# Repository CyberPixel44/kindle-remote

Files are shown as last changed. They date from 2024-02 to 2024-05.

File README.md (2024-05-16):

# Kindle Accessibility Remote Control
A project that allows for easy, low-latency wireless remote control of a Kindle e-reader running Koreader.
This project was inspired by my lovely Grandfather, Dr. A.M.V. Reddy, who still loves to read books to this day!

## Acknowledgement
Big thanks to user [bneo99](https://github.com/bneo99) for the base concept to build this project with!

# Setup

## Kindle

### Jailbreak
For most up to date jailbreak info, monitor the mobilread forums

\[UPDATED JUL 23]

[Forum Help](https://www.mobileread.com/forums/showthread.php?t=356872)
Download [relevant files](https://github.com/notmarek/LanguageBreak/releases/latest).
Instructions from [notmarek](https://github.com/notmarek/LanguageBreak):

Warnings

    ⚠️ This method will DELETE all content on your device. Backup important files.
    ⚠️ This method works up to firmware version 5.16.2.1.1. It is strongly suggested you upgrade to this firmware before starting.
    ⚠️ Do not update your firmware beyond 5.16.2.1.1 after jailbreaking with LanguageBreak, as future versions of the firmware patch it.
    ⚠️ Your device must have no password lock. Remove it before starting.

Before you start, make sure:

    Airplane Mode is ON
    The device (esp. the root folder) should have no .bin or update.bin.tmp.partial files before you start. This may be a pending OTA update. Delete them.

Jailbreaking your Kindle

    Type ;enter_demo into the Kindle search bar, press enter, then reboot the device.
    Once the device boots, dismiss the wifi selection dialog, type whatever you'd like into the text fields, then continue.
    Select Skip, then Standard, then Done
    The device will take a few minutes to go into demo mode. When it's done, use this gesture to access the main screen.
    Type ;demo into the Kindle search bar, then press enter to access the Demo Mode Configuration screen.
    Select the Sideload Content option.
    Connect your Kindle to a PC, then copy the contents of the LanguageBreak folder to the Kindle's root directory (if prompted, overrwrite the existing files).
    Eject, then unplug your Kindle, then return to the Demo Configuration Screen (using the method in step 5, if required).
    Select Resell Device, then confirm.
    As soon as the "Press the Power Button" screen appears, plug your Kindle back into your computer. (This is time sensitive, be quick.)
    Copy the contents of the LanguageBreak folder to the Kindle's root directory, again. (if prompted, overrwrite the existing files).
    After all files have been written, eject your Kindle, then press and hold the power button until the unit reboots.
    At this point, a language selection screen appears. Select 简体中文 (Chinese), which should appear above an entry called Pseudot and below Japanese.
    Your Kindle should reboot, and some log messages should appear in the top right-hand corner.

Applying the Hotfix

    After the device has rebooted, type ;uzb into the Kindle search bar to enable USB access within demo mode, then press enter.
    Connect the device to a PC and copy whichever Update_hotfix_languagebreak-{languge/locale}.bin file matches your language to the Kindle's root directory.
    Eject your Kindle, then ;dsts into the Kindle search bar to access the settings page. Locate the Update your Kindle option and press it, then confirm.

    Using your phone to translate the menus is helpful if you don't happen to be able to read Chinese.

This will reboot the device out of Demo mode. Your device may go into Managed mode after completing these steps. Managed devices have some settings greyed out, and ask the user to contact their system administrator. See below for steps on how to restore functionality (and the correct language) to your device.
Restoring the Correct Language and Exiting Managed Mode
If your kindle is not registered to an Amazon account:

    Type ;demo into the Kindle search bar.
    You will get a prompt with two buttons. Press the right-most button.
    The device will reboot. If all is well, your Kindle should have a folder named mkk in the root directory.

If your kindle is registered to an Amazon account:

    Enter ;enter_demo into the Kindle search bar, then reboot your device.
    The device will be back in full "Demo Mode". Use the same gesture to access the main screen.
    Enter ;demo into the Kindle search bar.
    Select Resell device, then confirm.
    The device will reboot. If all is well, your Kindle should have a folder named mkk in the root directory.

### WiFi
The Kindle won't allow you to connect to a network that has no Internet access by default.
In the topmost level of USB storage, create the file named `WIFI_NO_NET_PROBE` (all capitals, no extension, no contents).
This has to be done when Koreader is NOT launched.
Once you've connected the Kindle to the network once, you do not need to mess with the Kindle's default WiFi settings.
You may turn on Airplane mode if you are afraid of losing your jailbreak.

### Koreader
Before installing Koreader, you must install KUAL:
- Download `MR Package Installer` from [mobilread](https://www.mobileread.com/forums/showthread.php?t=225030).
- Extract. Copy all files to Kindle.
- Download `KUAL (coplate).` from [mobilread](https://www.mobileread.com/forums/showthread.php?t=225030).
- Extract it and put `Update_KUALBooklet_ff4134d_install.bin` in the `mrpackages` folder on the kindle and enter `;log mrpi` into the search bar (where you search for books).
- Read [this section at the end of this page to](https://github.com/koreader/koreader/wiki/Installation-on-Kindle-devices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) figure out which Kindle release you want to download.
- Download the latest Kindle package from this page.
- Unzip the whole archive into the Kindle's USB root directory

After installing Koreader, extract the contents of the `plugins` directory provided in this repository into the `koreader` folder of the Kindle found in the root of the Kindle. (`koreader/plugins/httpremote.koplugin/...`)

Once setup, you can find the plugin menu in the toolbar of Koreader. I suggest enabling autostart to start the listening server on the Kindle whenever turned on.
Turn on WiFi from Koreader ONLY! If you turn on WiFi in the main OS, you may run the risk of updating your Kindle and losing your jailbreak.
Your Koreader should automatically connect to the KindleRemote access point, as you configured it previously.

## ESP32
Any ESP32-based dev board that supports WiFi AP can be utilized for this project.
[LILYGO's T-Lion board](https://www.lilygo.cc/products/t-lion) works great for this project, as it comes with a 5-way joystick and 18650 li-ion charging circuit which is ideal for remote operations.



### Flashing KindleWiFiRemote.ino
If using the Arduino IDE,
1. In your Arduino IDE, go to File > Preferences
2. Enter the following into the “Additional Board Manager URLs” field:

   `https://raw.githubusercontent.com/espressif/arduino-esp32/gh-pages/package_esp32_index.json`
4. Open the Boards Manager: Go to Tools > Board > Boards Manager…
5. Search for ESP32 and press install button for the `“ESP32 by Espressif Systems“`
6. Select your Board in Tools > Board menu
   - For the case of the T-Lion, use ESP32 Wrover Kit (all versions)
7. Upload the code after selecting the COM port

### Dependencies

- [WiFi.h](https://github.com/espressif/arduino-esp32/blob/master/libraries/WiFi/src/WiFi.h)
- esp_wifi.h

### Configuration

1. **Wi-Fi AP Configuration:**
   - SSID: `KindleRemote`
   - Password: `password`

2. **ESP32 Pin Configuration:**
   These pins are default for the T-Lion
   - Forward Button: Pin 36
   - Toggle Button: Pin 39
   - Down Button: Pin 33
   - Backward Button: Pin 34
   - Up Button: Pin 32

3. **Kindle Static IP Address:**
   - The Kindle will normally get assigned the same default IP whenever connected to the ESP32's AP
   - To determine this (only has to be done once), open `Network Settings` in Koreader and click on `Network Info` to view the Kindle's local IP address
   - Replace the field with this local address: `Kindle IP: <local_IP>`
  
### 3D Printed Enclosure
To protect the ESP32 T-Lion from LILYGO, I designed 3D printable models that enclose the remote.
The STL files can be found in this repository as `Remote Bottom.stl` and `Remote Top.stl`



To print, simply slice them in slicing software such as [Ultimaker Cura](https://ultimaker.com/software/ultimaker-cura/) and print!




Mounting the base is tricky:

**⚠️ WARNING: The remote DOES NOT SLIDE IN! You will damage some traces and resistors!!!**
1) Insert one of the edges directly into the groove from above such that the remote sits at an angle with one edge completely inside the groove and the other sticking out.
2) Gently press down on the edge that is sticking out and pull back on the casing with your other hand to force the grooves around and on top of the other side.
3) Adjust the forwards and backwards position to seat the board properly.

# Usage

1. Turn on ESP-Remote.
2. Connect the Kindle to the Wi-Fi network named `KindleRemote` (or equivalent if changed).
3. Press the corresponding buttons on your ESP32 to control the Kindle remotely:

   - Forward Button (`buttonPinForward`): Page forward.
   - Toggle Button (`buttonPinToggle`): Toggle night mode.
   - Down Button (`buttonPinDown`): Decrease brightness.
   - Backward Button (`buttonPinBackward`): Page backward.
   - Up Button (`buttonPinUp`): Increase brightness.

## Latency

By viewing dynamic logs on Koreader, there is a ~20ms latency between when the button is pressed to when the page turn command is issued (wireless + software latency). However, same as with using the touchscreen, there is a considerable latency of ~200ms to ~600ms for the page to actually refresh due to e-ink hardware limitations of the Kindle itself!

## Disclaimer

This script is provided as-is, and you should use it responsibly. Ensure that you have the necessary permissions to control your Kindle remotely. The script assumes a certain setup and may require adjustments based on your specific environment. Jailbreaking your Kindle may void your warranty.

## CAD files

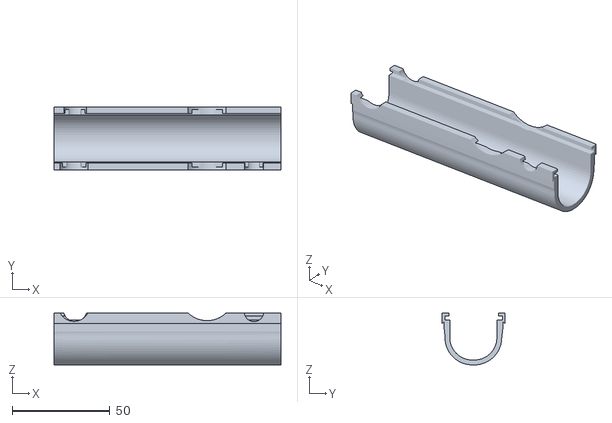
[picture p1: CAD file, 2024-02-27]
Remote Bottom.stl
116.0 x 32.0 x 26.5

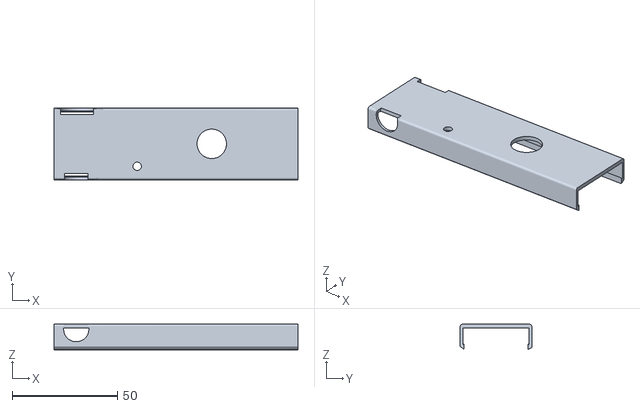
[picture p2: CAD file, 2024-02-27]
Remote Top.stl
116.0 x 34.0 x 12.2

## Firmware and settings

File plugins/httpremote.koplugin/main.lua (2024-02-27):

-- Original by https://github.com/bneo99

local Device =  require("device")
local UIManager = require("ui/uimanager")
local WidgetContainer = require("ui/widget/container/widgetcontainer")
local Event = require("ui/event")
local logger = require("logger")
local _ = require("gettext")

local HttpRemote = WidgetContainer:extend{
    name = "httpremote",
    is_doc_only = true,
}

function HttpRemote:init()
    self.port = G_reader_settings:readSetting("httpremote_port", "8080")
    self.autostart = G_reader_settings:isTrue("httpremote_autostart")

    if self.autostart then
        self:start()
    end

    self.ui.menu:registerToMainMenu(self)
end

function HttpRemote:initHttpMQ(host, port)
    local StreamMessageQueueServer = require("ui/message/streammessagequeueserver")
    if self.http_socket == nil then
        self.http_socket = StreamMessageQueueServer:new{
            host = host,
            port = port,
            receiveCallback = self:onRequest(),
        }
        self.http_socket:start()
        self.http_messagequeue = UIManager:insertZMQ(self.http_socket)
    end
    logger.info(string.format("connecting to calibre @ %s:%s", host, port))
end

function HttpRemote:onEnterStandby()
    logger.dbg("HttpRemote: onEnterStandby")
    self:stop()
end

function HttpRemote:onSuspend()
    logger.dbg("HttpRemote: onSuspend")
    self:stop()
end

function HttpRemote:onExit()
    logger.dbg("HttpRemote: onExit")
    self:stop()
end

function HttpRemote:onCloseWidget()
    logger.dbg("HttpRemote: onCloseWidget")
    self:stop()
end

function HttpRemote:onLeaveStandby()
    logger.dbg("HttpRemote: onLeaveStandby")
    if self.http_socket == nil then
        self:start()
    end
end

function HttpRemote:onResume()
    logger.dbg("HttpRemote: onResume")
    if self.http_socket == nil then
        self:start()
    end
end

function HttpRemote:start()
    -- Make a hole in the Kindle's firewall
    if Device:isKindle() then
        os.execute(string.format("%s %s %s",
            "iptables -A INPUT -p tcp --dport", self.port,
            "-m conntrack --ctstate NEW,ESTABLISHED -j ACCEPT"))
        os.execute(string.format("%s %s %s",
            "iptables -A OUTPUT -p tcp --sport", self.port,
            "-m conntrack --ctstate ESTABLISHED -j ACCEPT"))
    end

    self:initHttpMQ("*", self.port)
    logger.dbg("HttpRemote: Server listening on port " .. self.port)
end

function HttpRemote:stop()
    logger.info("HttpRemote: Stopping server...")

    if self.http_socket then
        self.http_socket:stop()
        self.http_socket = nil
    end
    if self.http_messagequeue then
        UIManager:removeZMQ(self.http_messagequeue)
        self.http_messagequeue = nil
    end

    logger.dbg("HttpRemote: Server stopped.")

    -- Plug the hole in the Kindle's firewall
    if Device:isKindle() then
        os.execute(string.format("%s %s %s",
            "iptables -D INPUT -p tcp --dport", self.port,
            "-m conntrack --ctstate NEW,ESTABLISHED -j ACCEPT"))
        os.execute(string.format("%s %s %s",
            "iptables -D OUTPUT -p tcp --sport", self.port,
            "-m conntrack --ctstate ESTABLISHED -j ACCEPT"))
    end
end

function HttpRemote:onRequest(host, port)
    -- NOTE: Closure trickery because we need a reference to *this* self *inside* the callback,
    --       which will be called as a function from another object (namely, StreamMessageQueue).
    local this = self
    return function(data, id_frame)
        local request = string.match(data, "[^\n]+") or ""
        logger.dbg("HttpRemote: Received request: " .. request)
        local params_string = request:match("%u+%s+%S+%?([^%s]+)%s+%S+") -- extract params
        logger.dbg("HttpRemote: Params: ", params_string)

        local params_arr = {}

        if params_string then
            for params in string.gmatch(params_string, "[^&]+") do
                -- Split each parameter string into key and value using string.match
                local key, value = string.match(params, "(.-)=(.*)")
                if key and value then
                    params_arr[key] = value
                end
            end
        end

        local response = "HTTP/1.1 200 OK" -- start of response header

        if params_arr["action"] == "nextpage" then
            this:turnPage(1)
        elseif params_arr["action"] == "prevpage" then
            this:turnPage(-1)
        elseif params_arr["action"] == "increasebrightness" then
            this:changeBrightness("IncreaseFlIntensity")
        elseif params_arr["action"] == "decreasebrightness" then
            this:changeBrightness("DecreaseFlIntensity")
        elseif params_arr["action"] == "togglefrontlight" then
            this:toggleSetting("ToggleFrontlight")
        elseif params_arr["action"] == "togglenightmode" then
            this:toggleSetting("ToggleNightMode")
        elseif params_arr["action"] == "fullrefresh" then
            this:refreshScreen()
        else
            response = response .. "\r\nContent-Type: text/html"
        end

        response = response .. "\r\n\r\n" -- end of response header

        -- response body (if available)
        -- if loadpage param is populated, load the html
        if next(params_arr) == nil or params_arr["loadpage"] then
            response = response .. [[
<html><body>
<p>
<a href="/?action=prevpage&loadpage=1">Previous Page</a>
<a href="/?action=nextpage&loadpage=1">Next Page</a>
<a href="/?action=increasebrightness&loadpage=1">Increase Brightness</a>
<a href="/?action=decreasebrightness&loadpage=1">Decrease Brightness</a>
<a href="/?action=togglefrontlight&loadpage=1">Toggle Frontlight</a>
<a href="/?action=togglenightmode&loadpage=1">Toggle Dark Mode</a>
<a href="/?action=fullrefresh&loadpage=1">Refresh Screen</a>
</p>
</body></html>
            ]]
        end
        logger.dbg("HttpRemote: Sending response: " .. response)
        this.http_socket:send(response, id_frame) -- send the response back to the client
    end
end

function HttpRemote:turnPage(pages)
    local top_wg = UIManager:getTopmostVisibleWidget() or {}
    if top_wg.name == "ReaderUI" then
        logger.dbg("HttpRemote: Sent event GotoViewRel " .. pages)
        self.ui:handleEvent(Event:new("GotoViewRel", pages))
    end
end

-- https://github.com/koreader/koreader/blob/master/frontend/dispatcher.lua
-- link for all supported actions

-- brightness actions
function HttpRemote:changeBrightness(action)
    logger.dbg("HttpRemote: Sent event " .. action .. " 1")
    self.ui:handleEvent(Event:new(action, 1))
    self.ui:handleEvent(Event:new("ShowFlDialog"))
end

-- setting actions (frontlight, nightmode)
function HttpRemote:toggleSetting(action)
    self.ui:handleEvent(Event:new(action))
end

function HttpRemote:refreshScreen()
    self.ui:handleEvent(Event:new("FullRefresh"))
end

function HttpRemote:addToMainMenu(menu_items)
    menu_items.httpremote = {
        text = _("HTTP Remote Control"),
        sorting_hint = ("tools"),
        sub_item_table = {
            {
                text_func = function()
                    if self.http_socket then
                        return _("Stop server")
                    else
                        return _("Start server")
                    end
                end,
                separator = true,
                callback = function()
                    if not self.http_socket then
                        self:start()
                    else
                        self:stop()
                    end
                end,
            },
            {
                text = _("Auto start server"),
                checked_func = function()
                    return self.autostart
                end,
                callback = function()
                    G_reader_settings:toggle("httpremote_autostart")
                    self.autostart = G_reader_settings:isTrue("httpremote_autostart")
                end,
            },
            {
                text_func = function()
                    return "Port: " .. self.port
                end,
                callback = function()
                    local InputDialog = require("ui/widget/multiinputdialog")
                    local port_dialog

                    port_dialog = InputDialog:new{
                        title = _("Set custom port"),
                        fields = {
                            {
                                text = self.port,
                                input_type = "number",
                                hint = _("Port"),
                            },
                        },
                        buttons =  {
                            {
                                {
                                    text = _("Cancel"),
                                    id = "close",
                                    callback = function()
                                        UIManager:close(port_dialog)
                                    end,
                                },
                                {
                                    text = _("OK"),
                                    callback = function()
                                        local port_dialog_input = port_dialog:getInputValue()
                                        if port_dialog_input ~= "" then
                                            local input_port = tonumber(port_dialog_input)
                                            if not input_port or input_port < 1 or input_port > 65355 then
                                                --default port
                                                input_port = 8080
                                            end
                                            self.port = input_port
                                            G_reader_settings:saveSetting("httpremote_port", input_port)

                                            --restart the server
                                            if self.http_socket then
                                                self:stop()
                                                self:start()
                                            end
                                        end
                                        UIManager:close(port_dialog)
                                    end,
                                },
                            },
                        },
                    }
                    UIManager:show(port_dialog)
                    port_dialog:onShowKeyboard()
                end,
            }
        },
    }
end

return HttpRemote

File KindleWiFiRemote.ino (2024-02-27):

#include <WiFi.h> // Include the Wi-Fi library
#include "esp_wifi.h"

const char *ssid = "KindleRemote"; // The name of the Wi-Fi network that will be created
const char *password = "password"; // The password required to connect to it

// kindle IP address
byte ip[] = {192, 168, 4, 2};
const char *host = "192.168.4.2";

#define buttonPinForward 36
#define buttonPinToggle 39
#define buttonPinDown 33
#define buttonPinBackward 34
#define buttonPinUp 32

bool lastButtonStateForward = HIGH;  // initial state is not pressed
bool lastButtonStateToggle = HIGH;   // initial state is not pressed
bool lastButtonStateDown = HIGH;     // initial state is not pressed
bool lastButtonStateBackward = HIGH; // initial state is not pressed
bool lastButtonStateUp = HIGH;       // initial state is not pressed

WiFiClient client;

void setup()
{

  setCpuFrequencyMhz(80); // decreases battery drain over 2x! (30mA) vs (63mA original)

  pinMode(buttonPinForward, INPUT_PULLUP);  // forward button pin
  pinMode(buttonPinToggle, INPUT_PULLUP);   // toggle button pin
  pinMode(buttonPinDown, INPUT_PULLUP);     // down button pin
  pinMode(buttonPinBackward, INPUT_PULLUP); // backward button pin
  pinMode(buttonPinUp, INPUT_PULLUP);       // up button pin

  Serial.begin(115200);
  delay(10);
  Serial.println('\n');

  WiFi.softAP(ssid, password); // Start the access point
  Serial.print("Access Point \"");
  Serial.print(ssid);
  Serial.println("\" started");

  Serial.print("IP address:\t");
  Serial.println(WiFi.softAPIP()); // Send the IP address of the ESP8266 to the computer

  delay(1000);
}

void loop()
{
  // debounce button code for perfect button listening :)
  // read button Forward
  bool buttonStateForward = digitalRead(buttonPinForward);
  if (buttonStateForward != lastButtonStateForward && buttonStateForward == LOW)
  {
    PageForward();
  }
  lastButtonStateForward = buttonStateForward;

  // read button Toggle
  bool buttonStateToggle = digitalRead(buttonPinToggle);
  if (buttonStateToggle != lastButtonStateToggle && buttonStateToggle == LOW)
  {
    ToggleNightMode();
  }
  lastButtonStateToggle = buttonStateToggle;

  // read button Down
  bool buttonStateDown = digitalRead(buttonPinDown);
  if (buttonStateDown != lastButtonStateDown && buttonStateDown == LOW)
  {
    DecreaseBrightness();
  }
  lastButtonStateDown = buttonStateDown;

  // read button Backward
  bool buttonStateBackward = digitalRead(buttonPinBackward);
  if (buttonStateBackward != lastButtonStateBackward && buttonStateBackward == LOW)
  {
    PageBackward();
  }
  lastButtonStateBackward = buttonStateBackward;

  // read button Up
  bool buttonStateUp = digitalRead(buttonPinUp);
  if (buttonStateUp != lastButtonStateUp && buttonStateUp == LOW)
  {
    IncreaseBrightness();
  }
  lastButtonStateUp = buttonStateUp;

  delay(50); // debounce delay
}

void sendRequest(const char *action)
{
  Serial.printf("\n[Connecting to %s ... ", host);
  if (client.connect(ip, 8080)) // port 8080 configured within the kindle
  {
    Serial.println("connected]");

    Serial.println("[Sending a request]"); // send the HTTP request to kindle
    client.print(String("GET /?action=") + action + " HTTP/1.1\r\n" +
                 "Host: " + host + "\r\n" +
                 "Connection: close\r\n" +
                 "\r\n");
    client.stop();
    Serial.println("\n[Disconnected]");
  }
  else
  {
    Serial.println("connection failed!]");
    client.stop();
  }
  delay(500);
}

void PageForward()
{
  Serial.println("Front Clicked!");
  sendRequest("nextpage");
}

void ToggleNightMode()
{
  Serial.println("Toggle Clicked!");
  sendRequest("togglenightmode");
}

void DecreaseBrightness()
{
  Serial.println("Down Clicked!");
  sendRequest("decreasebrightness");
}

void PageBackward()
{
  Serial.println("Back Clicked!");
  sendRequest("prevpage");
}

void IncreaseBrightness()
{
  Serial.println("Up Clicked!");
  sendRequest("increasebrightness");
}
